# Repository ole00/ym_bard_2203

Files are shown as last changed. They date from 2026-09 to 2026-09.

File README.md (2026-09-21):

# ym_bard_2203
A dual YM2203 sound chip board for Arduino Nano
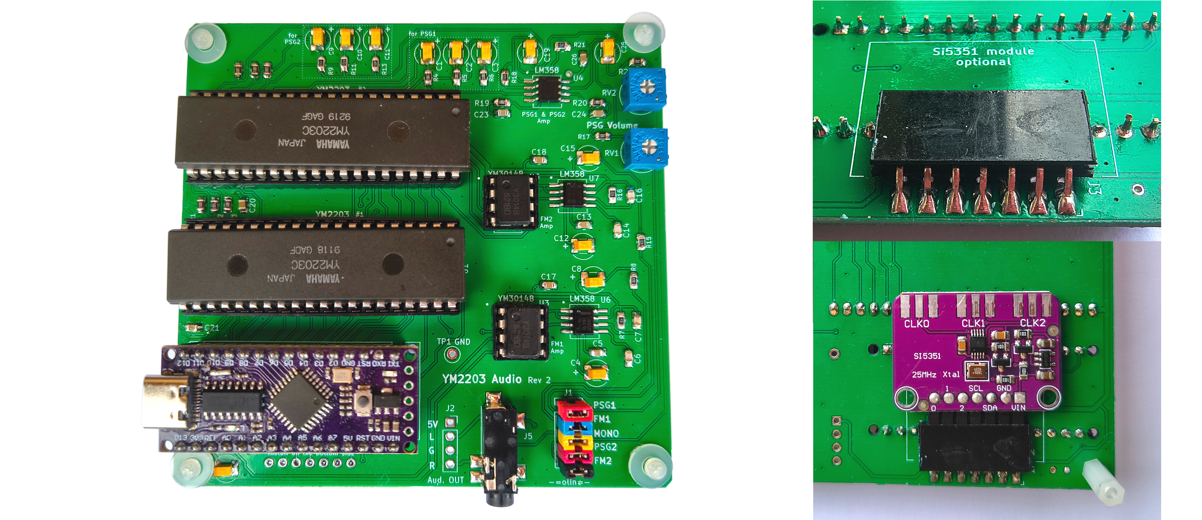
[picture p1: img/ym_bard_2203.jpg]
Board image ym_bard_2203


This is an open source/open hardware sound board with two YM2203 FM sound chips driven by Arduino Nano. 
The YM2203 FM chips were used in several arcade game boards made in 80's. 
The design of the YM Bard sound board was actually based on a schematic of an arcade game.

The board allows you to experiment with YM2203 sound chips by writing the chip's register values
from a PC over a serial port. It is also possible to stream an arcade game sound data over
a serial port from a PC based emulator and produce authentic sound and music of an arcade game.

YM2203 chips are register compatible with AY-3 PSG sound generator, therefore you can use FM Bard
to play AY-3 tunes as well.

Arduino selection
----------------------

The b(o)ard requires and Arduino Nano or a NANO clone. You can use 5V Atmel based Arduino Nano
or Renesas based Arduino NANO R4 or 3.3V ESP32-S3 based Arduino NANO or their clones.
The picture above uses a cheap LGT8F328P Nano board.

YM2203 requires an external clock of specific frequency to produce sounds. The clock can 
be generated either by Arduino NANO or by an external Si5351 module connected on the bottom
side of the YM Bard. The Si5351 module is optional, however the Atmel based Arduino NANO can
only produce limited selection of clock frequencies, so it is recommended to use the module 
in such case. NANO R4 and ESP32-S3 based Arduino NANO can produce various frequencies 
and the clock module is not required for driving the FM clock at 3 MHz.

Audio data streaming
----------------------
To stream data to YM Bard use 'ym2203_streamer.ino' Arduino sketch located in 'arduino-src'
subdirectory and upload it to your Arduino NANO. Use Arduino IDE PC software to upload the sketch.
If you use Arduino NANO ESP32-S3 then make sure to install "esp32 by Espressif" version 3.3.X
board support in Arduino IDE Board manager before you do the upload.

The sketch reads binary data sent from the connected PC serial port (115200 baud rate)
and writes the data to the parallel data bus of the FM chips. The stream format supports two types of packets: 
3 byte packet and 12 byte packet.

**3 byte packet**

* 1st byte: bits 7-4: 0xF, bit 3: 0, bits 2-0: chip selection (0 selects the 1st YM2203, 1 selects the 
  2nd YM2203).
* 2nd byte: register address
* 3rd byte: register value

**12 byte packet**
* 1st byte: bits 7-4: 0xF, bit 3: 1, bits 2-0: chip selection (0 selects the 1st YM2203, 1 selects the 
  2nd YM2203).
* byte 2 to byte 12: register values of register 0 to register 10.

3 byte packet allows you to write single arbitrary register. It is flexible, but requires
more data per register to be sent compared to 12 byte packet. 12 byte packets basically sends
multiple PSG registers in one go, saving the serial line bandwidth.

To start streaming open the serial port of your Arduino NANO and write the packets to
the serial port in binary format.

Example playback
-----------------
If you use Linux you can try to connect YM Bard to Ghost'n Goblins arcade emulator located here:

https://github.com/ole00/arcade_emu_gng

Pass the serial port device of the YM Bard to the emulator with parameter '-fm [device name]'
when starting the emulator. For example add '-fm /dev/ttyUSB0' parameter. If your Arduino NANO
has the 'ym2203_streamer.ino' uploaded, then the emulator and connected YM Bard should start
producing tunes from the arcade game.

Board production
------------------
To produce YM Bard you'll need some basic SMT component soldering skills. All components can be
soldered by hand with a modern soldering iron with controllable temperature (like TS100
or similar) set to 330 to 350 deg C. The list of components is located in 'bom_fm_bard_2203.csv'
file. The PCB can be fabricated by jlcpcb.com, pcbway.com, allpcb.com or other online services. 
Use the zip archive stored in the 'gerbers' directory and upload it to the manufacturer's web site
of your choice. Upload the 'ym2203_r2_fab.zip' archive and set the following parameters (if required). 
  
  * 2 layer board
  * PCB Thickness: 1.6, or 1.2 mm
  * Copper Weight: 1
  * The rest of the options can stay default or choose whatever you fancy (colors, finish etc.)

When populating components either start with the smallest SMT parts first (resistors and small capacitors)
or start with the SOIC-8 LM358 OpAmps so that you have plenty of room for the soldering iron tip.
After that, solder the bigger 10uF capacitors - check the capacitor's polarity. The SMT caps use
the stripe on the positive (+) side, the electrolytic TH caps use the stripe on the negative (-) side.
Solder the through hole parts and the audio connector at the end. 
I strongly recommend to use IC sockets for YM2203C chips and also for YM3014B chips.
IC sockets ensure you do not overheat and damage the chips while soldering. They will also allow
you to swap the chip in case you get faulty chips sourced from Aliexpress (not uncommon).

If you are not familiar with SMT soldering check some YT videos and use one of the YM Bard PCB 
as a practice board to solder some SMT resistors and caps. It is not that hard, just requires
good tweezers, use of soldering flux and a bit of practice.

Audio output
--------------
The output audio signal is routed through J1 'mixing' header. The header is supposed to be populated
by jumper caps that connect individual sound sources to either a stereo or mono output. The sound
sources are FM1, PSG1 (both coming from the YM2203 #1) and FM2 and PSG2 (both coming from YM2203 #2).
Yes, YM2203 chips have separate output for FM channels and for the PSG channels. The PSG channel
volume can be adjusted (relatively to the FM channels) by RV1 and RV2 potentiometers.
The middle jumper position on J1 - when shorted - joins all outputs to a mono signal (routed to
both Left and Right audio channel). By default the jumpers are supposed to be all connected (see the 
YM bard image), but you can undo them if you want to disable certain audio sources from the final output. 
Additionally/optionally you might want to design/add a post processing audio option to YM Bard 
by connecting it via J1 and J2 header (has GND and 5V pins). The output is not amplified but
is capable of driving small headphones via J5 headphone socket. If you want louder sound use
PC speakers with an amplifier connected to the headphone socket.

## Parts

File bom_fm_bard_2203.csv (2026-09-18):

Reference | Value | Qty | Notes
C1,C2,C3,C4,C8,C9,C10,C11,C12,C15,C19,C22,C25 | 10uF | 13 | SMT 1210 or SMT 1208
C5,C13,C17,C18,C20,C21,C23,C24,C26 | 0.1uF | 9 | SMT 0805
C6,C7,C14,C16 | 1nF | 4 | SMT 0805
J1 | AUD_MIX | 1 | header pin 2x5 2.54mm pin pitch TH
J5 | AudioJack3 | 1 | PJ-328 Audio jack
R1,R2,R3,R10,R12,R14,R17,R22 | 1k | 8 | SMT 0805
R4,R5,R6,R7,R8,R9,R11,R13,R15,R16,R18,R21 | 4k7 | 12 | SMT 0805
R19,R20 | 10k | 2 | SMT 0805
RV1,RV2 | 2k | 2 | potentiometer 3362P 2k
U1,U2 | YM2203 | 2 | YM2203C Aliexpress
U3,U5 | YM3014B | 2 | DAC for Yamaha FM chips
U4,U6,U7 | LM358 | 3 | SMT SOIC-8
- | jumper cap | 5 | 2.54mm jumper cap (for audio 'mixer')

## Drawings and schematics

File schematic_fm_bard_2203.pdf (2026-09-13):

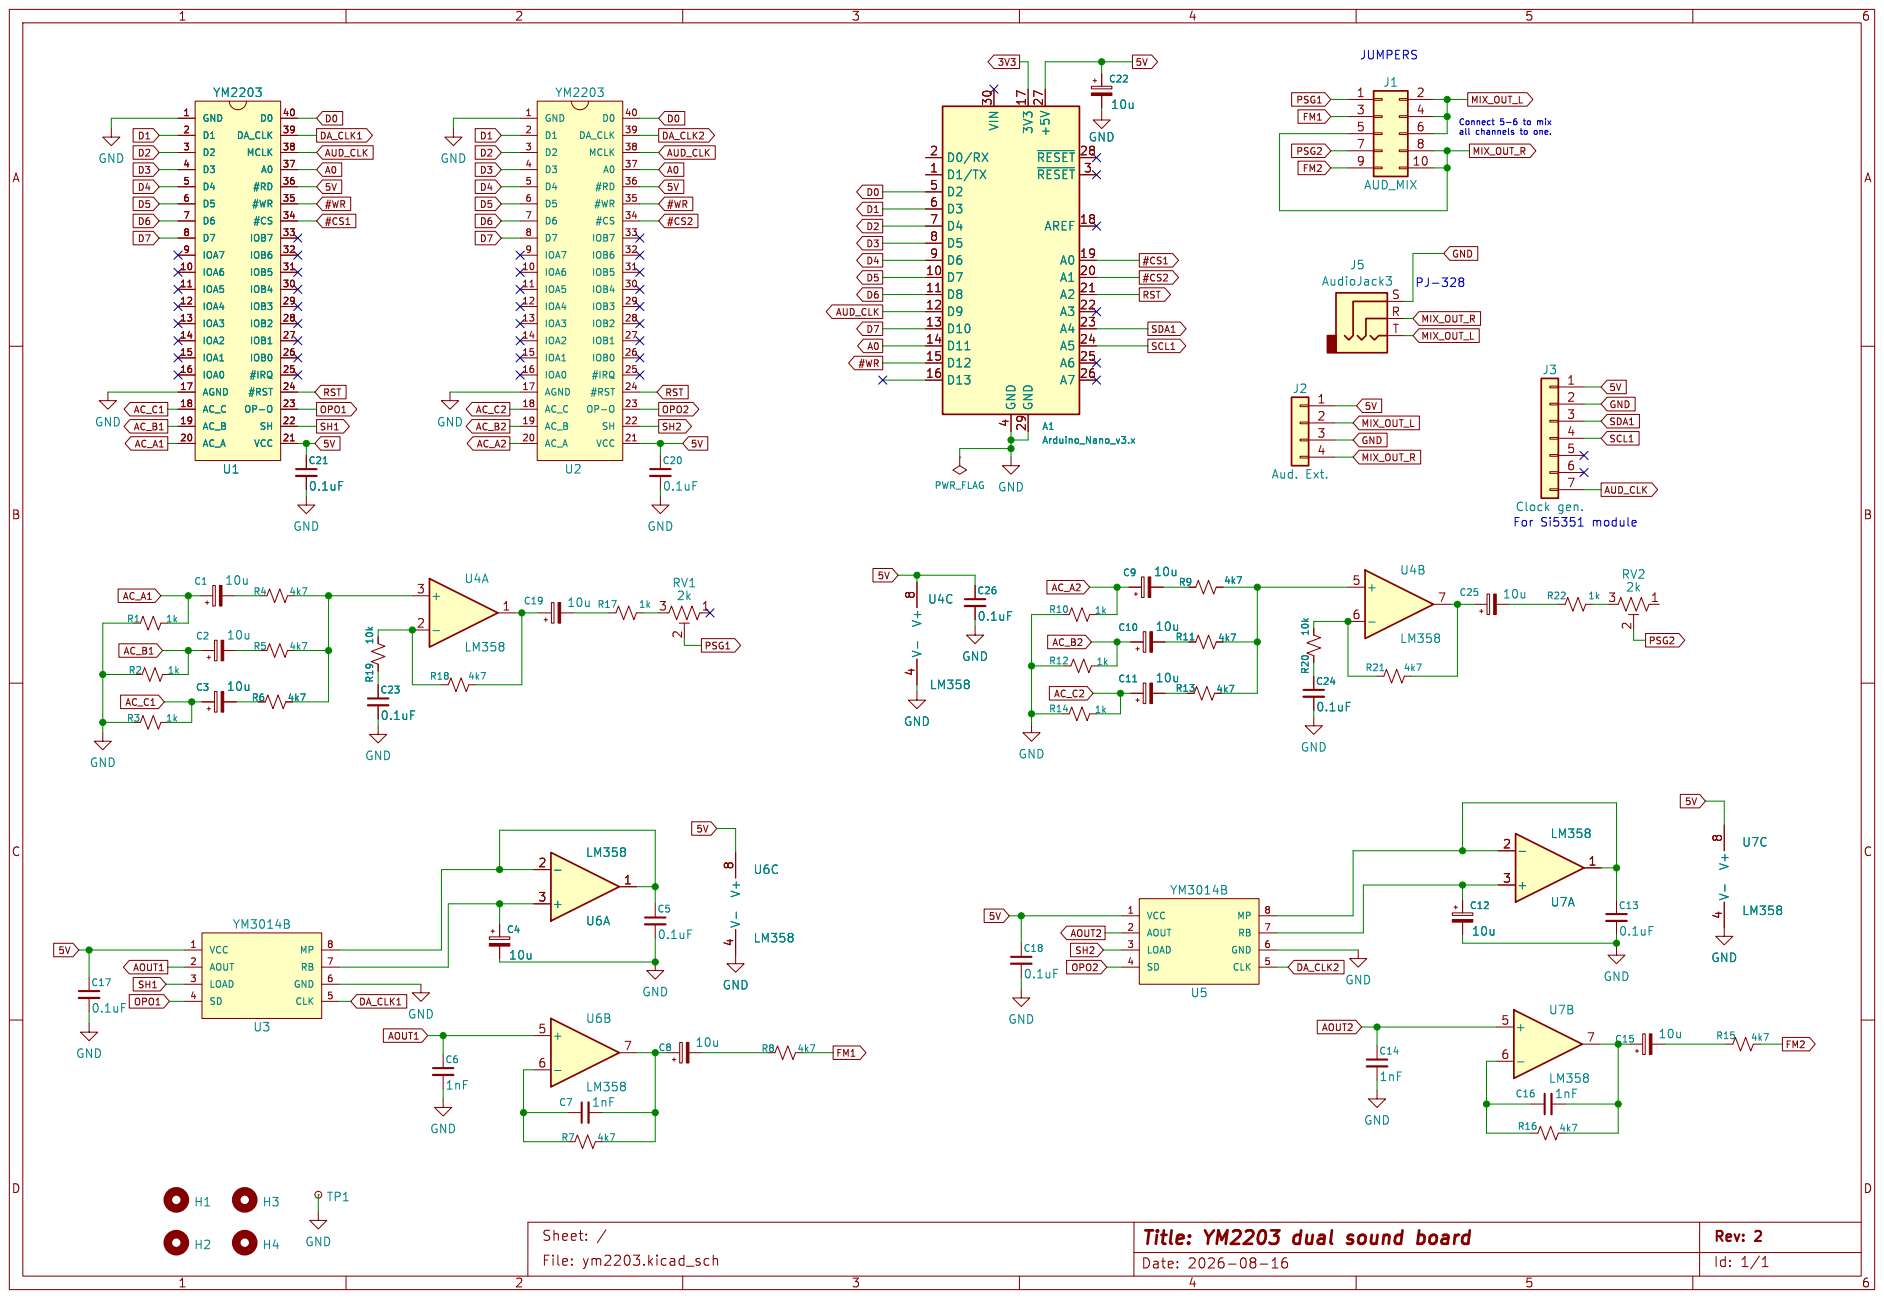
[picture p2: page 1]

Id: 1/1 Title: YM2203 dual sound board

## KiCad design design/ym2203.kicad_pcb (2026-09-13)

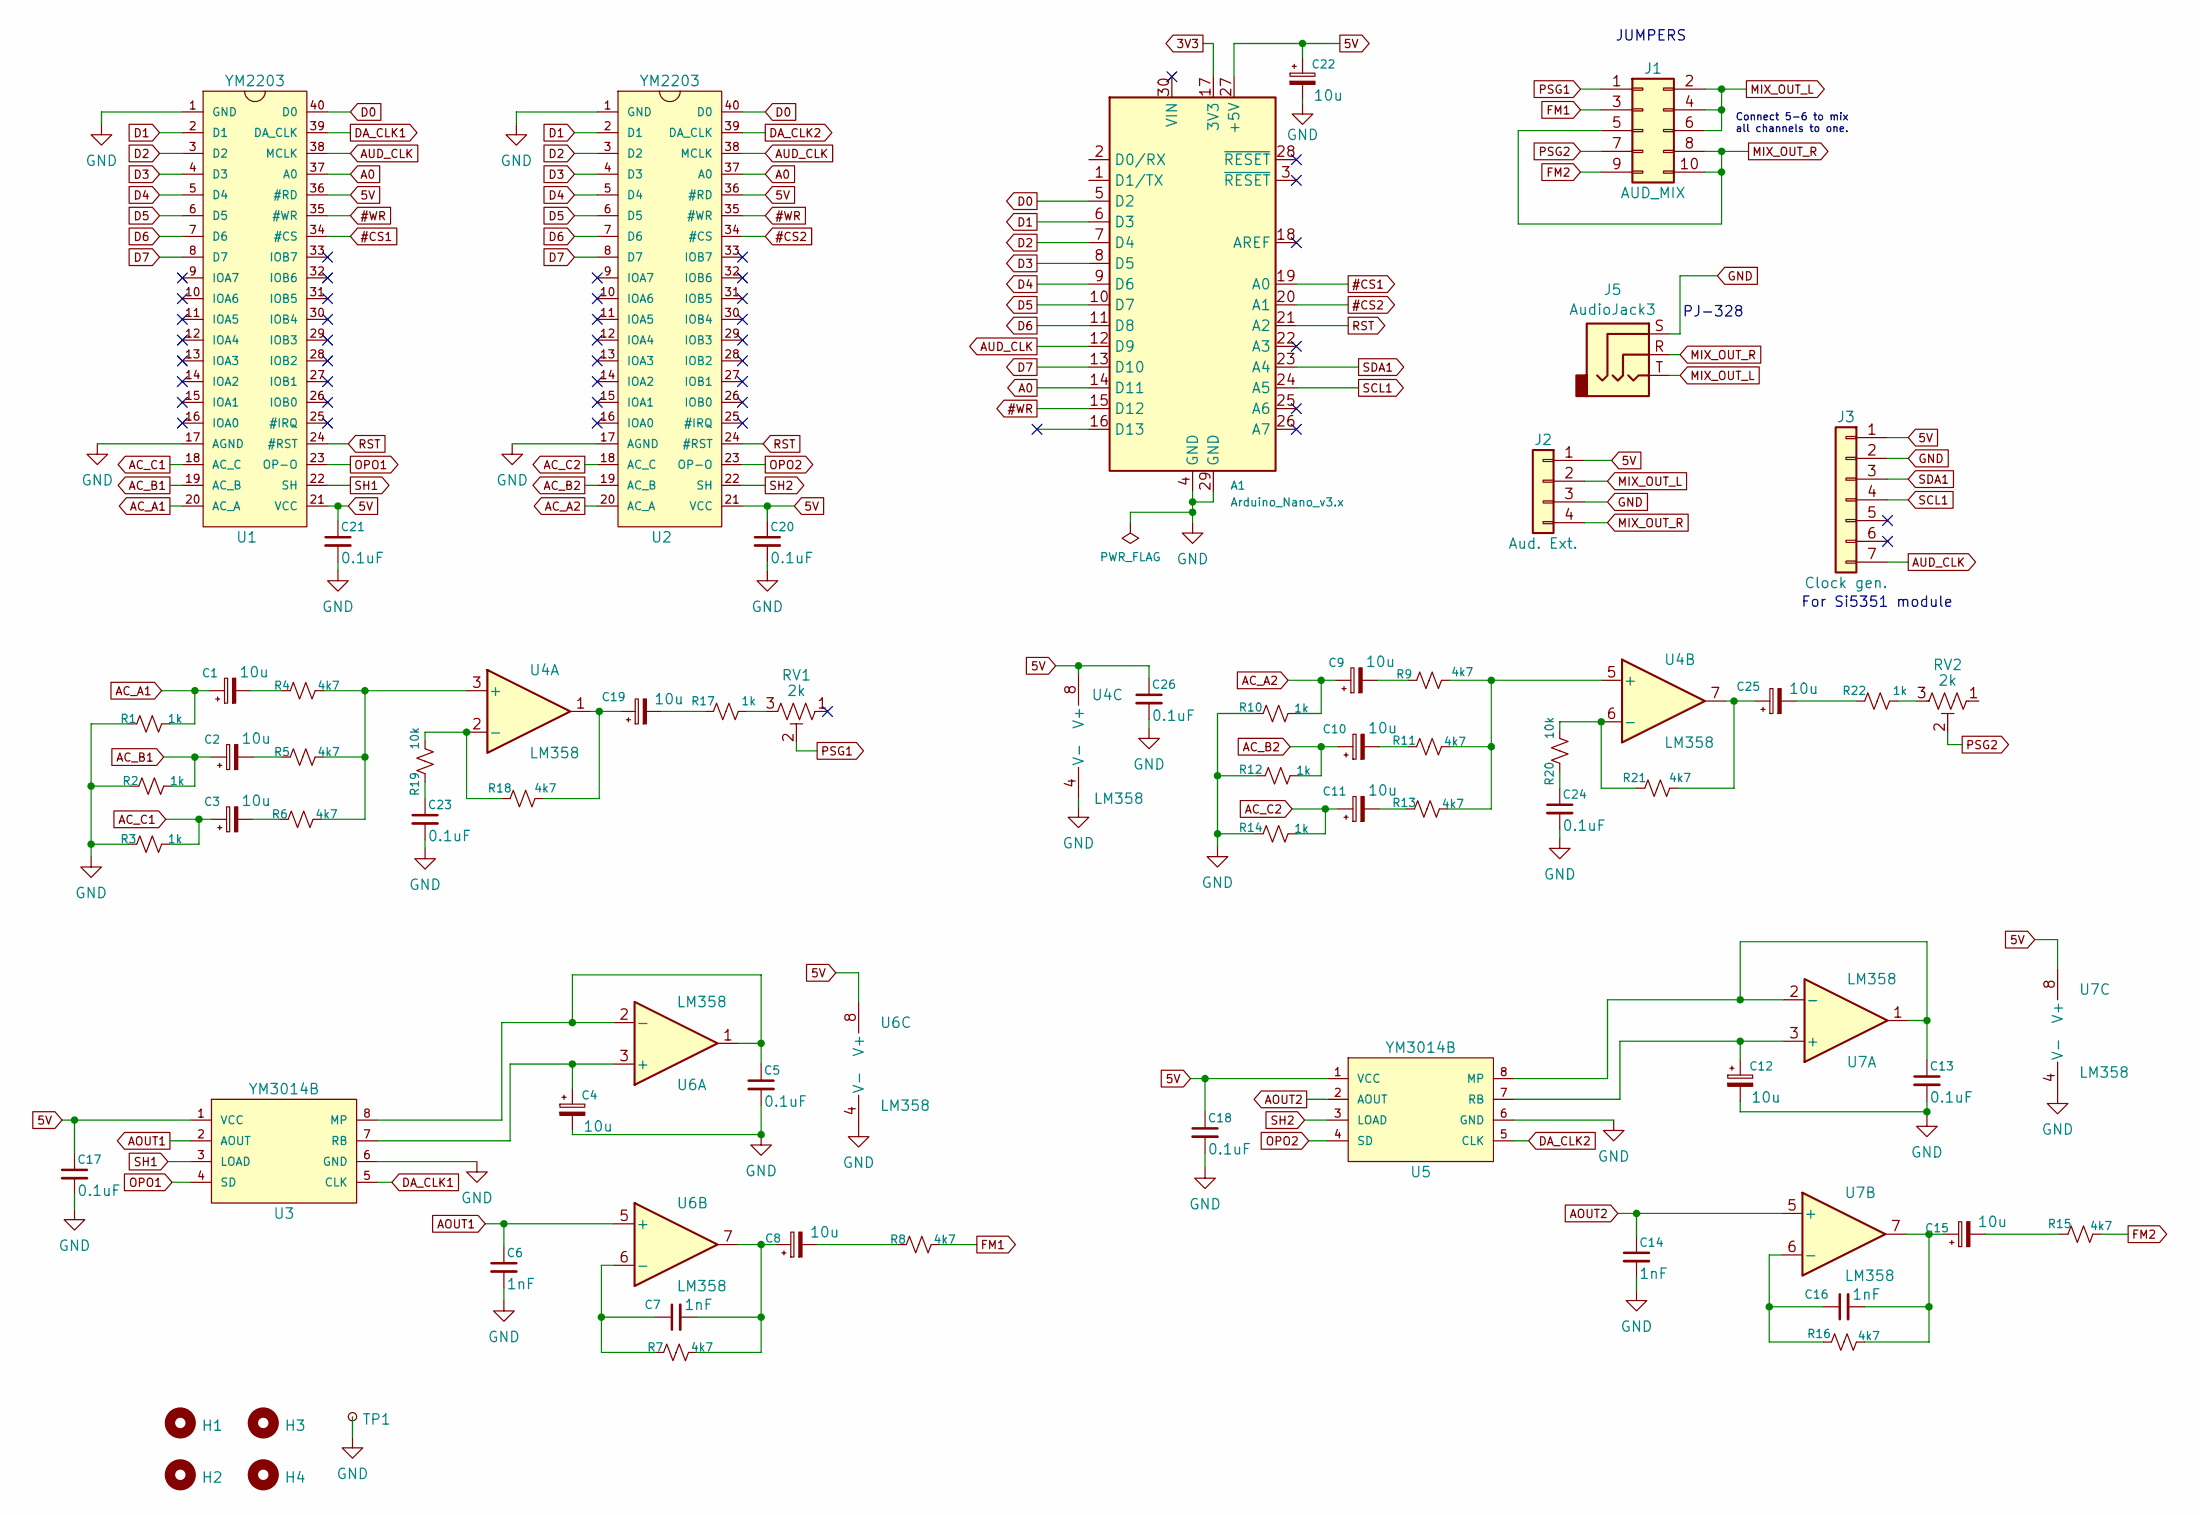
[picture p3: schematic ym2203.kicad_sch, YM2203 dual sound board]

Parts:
A1: Arduino_Nano_v3.x; Arduino_Nano_WithMountingHoles
C1, C2, C3, C4, C8, C9, C10, C11, C12, C15, C19, C22, C25: 10u; C_1210_3225Metric_dual_TH
C5, C13, C17, C18, C20, C21, C23, C24, C26: 0.1uF; C_0805_2012Metric_Pad1.18x1.45mm_HandSolder
C6, C7, C14, C16: 1nF; C_0805_2012Metric_Pad1.18x1.45mm_HandSolder
H1, H2, H3, H4: MountingHole; MountingHole_3.2mm_M3
J1: AUD_MIX; PinHeader_2x05_P2.54mm_Vertical
J2: Aud. Ext.; PinSocket_1x04_P2.54mm_Vertical
J3: Clock gen.; pad_array_th_1x07_P2.54mm
J5: AudioJack3; Jack_3.5mm_CUI_SJ2-3593D-SMT_Horizontal
R1, R2, R3, R10, R12, R14, R17, R22: 1k; R_0805_2012Metric_Pad1.20x1.40mm_HandSolder
R4, R5, R6, R7, R8, R9, R11, R13, R15, R16, R18, R21: 4k7; R_0805_2012Metric_Pad1.20x1.40mm_HandSolder
R19, R20: 10k; R_0805_2012Metric_Pad1.20x1.40mm_HandSolder
RV1, RV2: 2k; Potentiometer_Bourns_3339P_Vertical_HandSoldering
TP1: TestPoint_Small; TestPoint_Loop_D2.50mm_Drill1.0mm
U1, U2: YM2203; DIP-40_W15.24mm_LongPads
U3, U5: YM3014B; DIP-8_W7.62mm
U4, U6, U7: LM358; SO-8_5.3x6.2mm_P1.27mm

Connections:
3V3: A1.17 (3V3)
5V: A1.27 (+5V), C17.1, C18.1, C20.1, C21.1, C22.1, C26.1, J2.1, J3.1, U1.21 (VCC), U1.36 (#RD), U2.21 (VCC), U2.36 (#RD), U3.1 (VCC), U4.8 (V+), U5.1 (VCC), U6.8 (V+), U7.8 (V+)
#CS1: A1.19 (A0), U1.34 (#CS)
#CS2: A1.20 (A1), U2.34 (#CS)
#WR: A1.15 (D12), U1.35 (#WR), U2.35 (#WR)
A0: A1.14 (D11), U1.37 (A0), U2.37 (A0)
AC_A1: C1.1, R1.2, U1.20 (AC_A)
AC_A2: C9.1, R10.2, U2.20 (AC_A)
AC_B1: C2.1, R2.2, U1.19 (AC_B)
AC_B2: C10.1, R12.2, U2.19 (AC_B)
AC_C1: C3.1, R3.2, U1.18 (AC_C)
AC_C2: C11.1, R14.2, U2.18 (AC_C)
AOUT1: C6.1, U3.2 (AOUT), U6.5 (+)
AOUT2: C14.1, U5.2 (AOUT), U7.5 (+)
AUD_CLK: A1.12 (D9), J3.7, U1.38 (MCLK), U2.38 (MCLK)
D0: A1.5 (D2), U1.40 (D0), U2.40 (D0)
D1: A1.6 (D3), U1.2 (D1), U2.2 (D1)
D2: A1.7 (D4), U1.3 (D2), U2.3 (D2)
D3: A1.8 (D5), U1.4 (D3), U2.4 (D3)
D4: A1.9 (D6), U1.5 (D4), U2.5 (D4)
D5: A1.10 (D7), U1.6 (D5), U2.6 (D5)
D6: A1.11 (D8), U1.7 (D6), U2.7 (D6)
D7: A1.13 (D10), U1.8 (D7), U2.8 (D7)
DA_CLK1: U1.39 (DA_CLK), U3.5 (CLK)
DA_CLK2: U2.39 (DA_CLK), U5.5 (CLK)
FM1: J1.3, R8.2
FM2: J1.9, R15.2
GND: A1.4 (GND), A1.29 (GND), C4.2, C5.2, C6.2, C12.2, C13.2, C14.2, C17.2, C18.2, C20.2, C21.2, C22.2, C23.2, C24.2, C26.2, J2.3, J3.2, J5.S, R1.1, R2.1, R3.1, R10.1, R12.1, R14.1, TP1.1, U1.1 (GND), U1.17 (AGND), U2.1 (GND), U2.17 (AGND), U3.6 (GND), U4.4 (V-), U5.6 (GND), U6.4 (V-), U7.4 (V-)
MIX_OUT_L: J1.2, J1.4, J1.6, J2.2, J5.T
MIX_OUT_R: J1.5, J1.8, J1.10, J2.4, J5.R
unnamed: C1.2, R4.1
unnamed: C2.2, R5.1
unnamed: C3.2, R6.1
unnamed: C7.2, C8.1, R7.2, U6.7
unnamed: C8.2, R8.1
unnamed: C9.2, R9.1
unnamed: C10.2, R11.1
unnamed: C11.2, R13.1
unnamed: C15.1, C16.2, R16.2, U7.7
unnamed: C15.2, R15.1
unnamed: C19.1, R18.2, U4.1
unnamed: C19.2, R17.1
unnamed: C23.1, R19.1
unnamed: C24.1, R20.1
unnamed: C25.1, R21.2, U4.7
unnamed: C25.2, R22.1
unnamed: R17.2, RV1.3
unnamed: R22.2, RV2.3
unnamed: C5.1, U3.8 (MP), U6.1, U6.2 (-)
unnamed: C4.1, U3.7 (RB), U6.3 (+)
unnamed: R4.2, R5.2, R6.2, U4.3 (+)
unnamed: R18.1, R19.2, U4.2 (-)
unnamed: R9.2, R11.2, R13.2, U4.5 (+)
unnamed: R20.2, R21.1, U4.6 (-)
unnamed: C13.1, U5.8 (MP), U7.1, U7.2 (-)
unnamed: C12.1, U5.7 (RB), U7.3 (+)
unnamed: C7.1, R7.1, U6.6 (-)
unnamed: C16.1, R16.1, U7.6 (-)
OPO1: U1.23 (OP-O), U3.4 (SD)
OPO2: U2.23 (OP-O), U5.4 (SD)
PSG1: J1.1, RV1.2
PSG2: J1.7, RV2.2
RST: A1.21 (A2), U1.24 (#RST), U2.24 (#RST)
SCL1: A1.24 (A5), J3.4
SDA1: A1.23 (A4), J3.3
SH1: U1.22 (SH), U3.3 (LOAD)
SH2: U2.22 (SH), U5.3 (LOAD)

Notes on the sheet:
For Si5351 module
PJ-328
JUMPERS
Connect 5-6 to mix all channels to one.

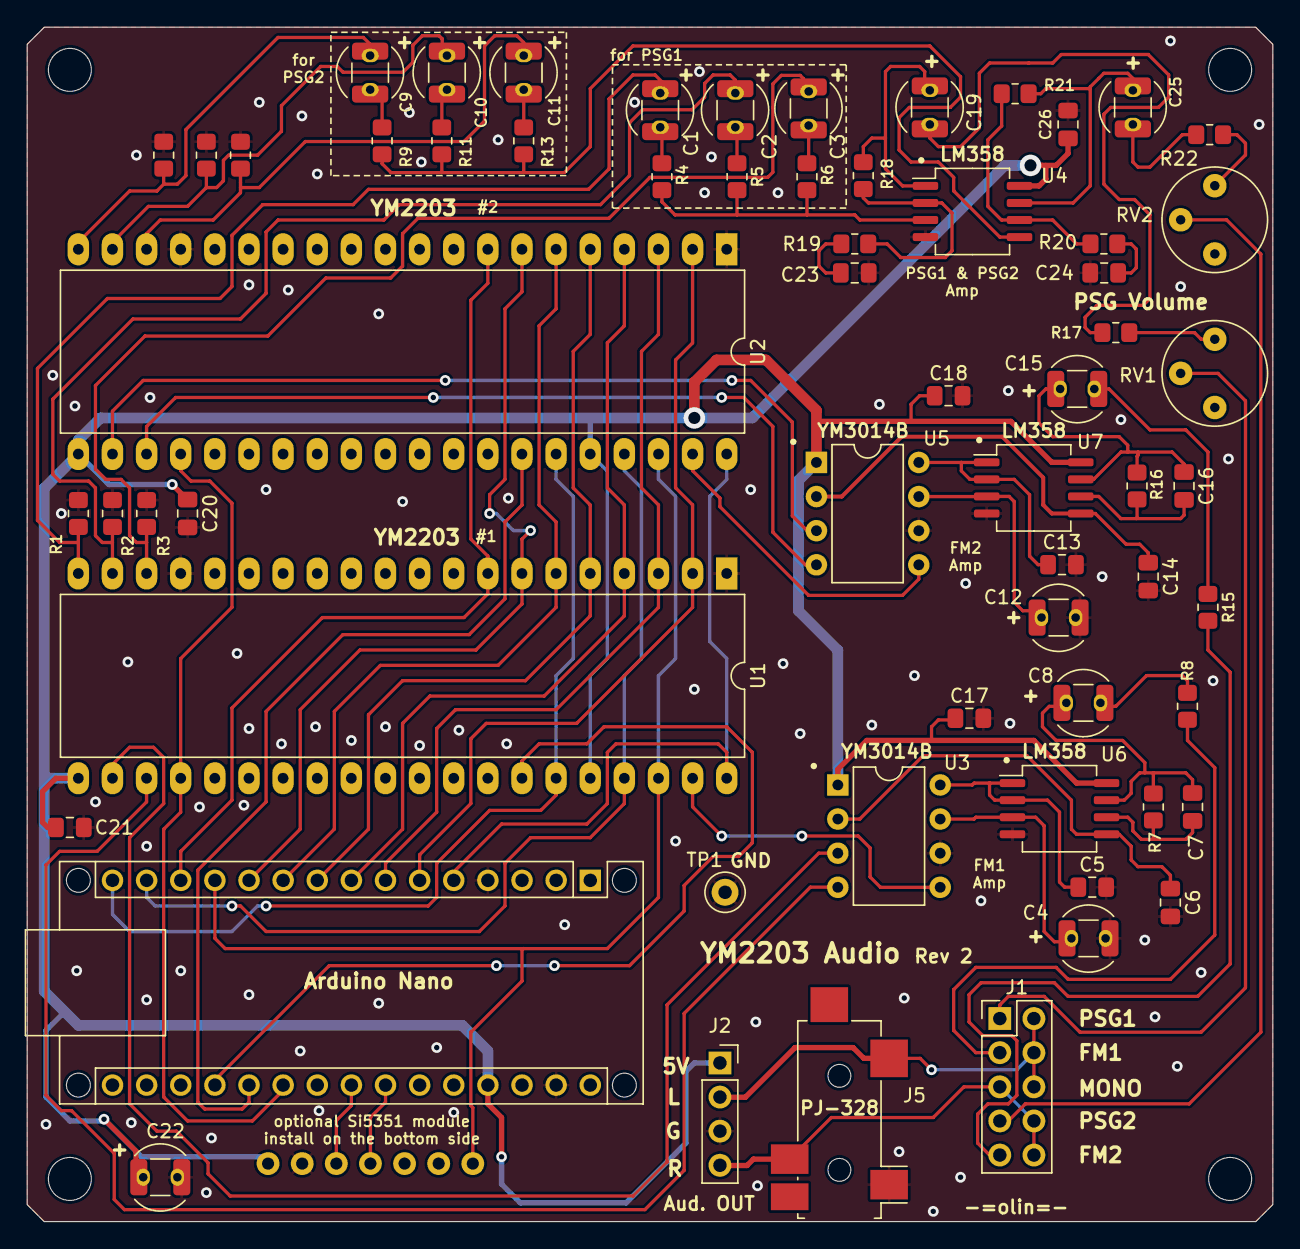
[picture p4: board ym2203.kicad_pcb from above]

Board: 2 copper layers, 92.7 x 88.9 mm, 67 parts (1 on the bottom side), 66 nets.

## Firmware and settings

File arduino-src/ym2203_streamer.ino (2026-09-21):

// YM2203 streamer for Arduino Nano and Arduino NANO-ESP32 and compatible
// Streams up to two YM2203 chips.

#include "si5351.h"

#ifdef CONFIG_IDF_TARGET_ESP32S3
#define USE_ESP32S3
#endif

#ifdef _RENESAS_RA_
#include "pwm.h"
#define USE_RENESAS_RA
#endif


#ifdef USE_ESP32S3
#define USE_FAST_MCU
#define PIN_CS1 1
#define PIN_CS2 2

#define PIN_WR  47
#define PIN_RESET 3

#define PIN_DB0 5
#define PIN_DB1 6
#define PIN_DB2 7
#define PIN_DB3 8
#define PIN_DB4 9
#define PIN_DB5 10
#define PIN_DB6 17
#define PIN_DB7 21
#define PIN_ADDR 38
#define PIN_YM_CLK 18

#define PIN_BOARD_LED 45
#define LED_INVERSE 1

#elif defined(USE_RENESAS_RA)
// Renesas based Arduino NANO R4
#define USE_FAST_MCU
#define PIN_CS1 A0
#define PIN_CS2 A1

#define PIN_WR  12
#define PIN_RESET A2

#define PIN_DB0 2
#define PIN_DB1 3
#define PIN_DB2 4
#define PIN_DB3 5
#define PIN_DB4 6
#define PIN_DB5 7
#define PIN_DB6 8
#define PIN_DB7 10
#define PIN_ADDR 11
#define PIN_YM_CLK 9

#define PIN_BOARD_LED LED_BUILTIN
#define LED_INVERSE 0
#else
// Atmega based arduinos
#define PIN_CS1 A0
#define PIN_CS2 A1

#define PIN_WR  12
#define PIN_RESET A2

#define PIN_DB0 2
#define PIN_DB1 3
#define PIN_DB2 4
#define PIN_DB3 5
#define PIN_DB4 6
#define PIN_DB5 7
#define PIN_DB6 8
#define PIN_DB7 10
#define PIN_ADDR 11
#define PIN_YM_CLK 9

#define PIN_BOARD_LED LED_BUILTIN
#define LED_INVERSE 0

#define M_D0 (1 << PIN_DB0)
#define M_D1 (1 << PIN_DB1)
#define M_D2 (1 << PIN_DB2)
#define M_D3 (1 << PIN_DB3)
#define M_D4 (1 << PIN_DB4)
#define M_D5 (1 << PIN_DB5)
#define M_D6 (1 << (PIN_DB6 - 8))
#define M_D7 (1 << (PIN_DB7 - 8))
#define M_WR (1 << (PIN_WR - 8))
#define M_ADDR (1 << (PIN_ADDR - 8))

#endif


#define MAGIC 0xF3

#define XON  0x11
#define XOFF 0x13

// Hysteresis Levels for a 256-byte buffer
#define BUFFER_HIGH_WATER 96 // Send XOFF if buffer fills past this
#define BUFFER_LOW_WATER  14  // Send XON if buffer empties below this

#define LOCAL_FIFO_SIZE 128
uint8_t localFifo[LOCAL_FIFO_SIZE];
uint8_t fifoHead = 0;
uint8_t fifoTail = 0;
uint8_t parserState = 0;


bool masterTxPaused = false; // Tracks if we told Linux to stop

// Set up 3MHz clock for YM2203 on pin D9
#ifdef USE_ESP32S3
void setupPwm() {
    // 1. MANDATORY ELEMENT: Force the LEDC system driver to hook into 
    // the 80 MHz APB clock instead of the default 40 MHz XTAL clock source.
    ledcSetClockSource(LEDC_AUTO_CLK); 

    uint32_t frequency = 3000000; // Exactly 3,000,000 Hz
    uint8_t resolution_bits = 1;   // 4-bit resolution 

    // 2. Attach the pin to the high-speed clock bus
    ledcAttach(PIN_YM_CLK, frequency, resolution_bits);

    // 3. Write a 50% duty cycle square wave
    ledcWrite(PIN_YM_CLK, 1); 
}
#elif defined(USE_RENESAS_RA)
 //Arduino NANO R4 (Renesas ARM at 5V)
 void setupPwm() {
    PwmOut* high_speed_clock = new PwmOut(PIN_YM_CLK);

    // Configure HS clock via the core's native raw microsecond parameter initialization.
    // Arguments: (period_units, pulse_width_units, raw_mode_flag, timer_divider)
    // To get 3MHz signal from the 48MHz background bus clock (PCLKD):
    // Period Cycles = 48,000,000 / 3,000,000 = 16 cycles
    // Duty Cycle (50% Square Wave) = 16 / 2 = 8 cycles
    uint32_t period_cycles = 16;
    uint32_t pulse_cycles = 8;

    // Passing 'true' alerts the driver to use raw CPU clock cycles 
    // instead of abstract microsecond timing blocks.
    bool success = high_speed_clock->begin(
        period_cycles, 
        pulse_cycles, 
        true, 
        TIMER_SOURCE_DIV_1
    );
 }
#else
// Atmega 328p or compatible
// Can't produce 3MH clock, the closest match is 3.2MHz.
void setupPwm() {
  // Set Pin 9 (Port B, Pin 1) as an OUTPUT
  pinMode(PIN_YM_CLK, OUTPUT);

  // 1. Clear Timer 1 Control Registers
  TCCR1A = 0;
  TCCR1B = 0;
  TCNT1  = 0;

  // 2. Set Fast PWM mode with ICR1 as the TOP value (Mode 14)
  // WGM13 and WGM12 are in TCCR1B. WGM11 is in TCCR1A.
  TCCR1A |= (1 << WGM11);
  TCCR1B |= (1 << WGM13) | (1 << WGM12);

  // 3. Set Toggle/Clear behavior for Channel A (Pin 9)
  // This toggles Pin 9 on every match to create the 8 MHz wave
  TCCR1A |= (1 << COM1A1);

  // 4. Set TOP to 1. 
  // Formula: Frequency = Clock / (Prescaler * (1 + TOP))
  // 8,000,000 = 16,000,000 / (1 * (1 + 1))
  //ICR1 = 1; // 8MHz
  //ICR1 = 2; // 5.333 MHz
  //ICR1 = 3; // 4.0 MHz
  ICR1 = 4; // 3.2 MHz
  //ICR1 = 5; // 2.66 MHz
  //ICR1 = 6; // 2.28 MHz
  //ICR1 = 7; // 2 MHz
  //ICR1 = 8; // 1.77 MHz
  //ICR1 = 9; // 1.6 MHz
  //ICR1 = 10; // 1.45 MHz


  // 5. Set the Match value to 0 to trigger the toggle
  OCR1A = 1; // set to 0 for 8 MHz, set to 1 for up to 3.2 MHz, set to 2 for lower

  // 6. Start the timer with NO prescaler (divide clock by 1)
  TCCR1B |= (1 << CS10);
}
#endif


// Setup clock for YM2203. Use Si5251 clock generator if present, or else
// try to generate 3 MHz clock on pin D9.
static void setupClockOutput() {
    // Check whether we have Si5351 programmable clock.
    // If so, set 3 Mhz clock.
    if (Si5351_init()) {
        Si5351_set_3_mhz();
        digitalWrite(PIN_BOARD_LED, LED_INVERSE ? LOW : HIGH);
    } else
    // Fallback method of using PWM based clock.
    // Closest possible frequency is 3.2 MHz on Atmel arduinos, so music is a bit higher pitch.
    // ESP32-S3 based Arduinos can generate precise 3MHz clock frequency on their own.
    {    
        digitalWrite(PIN_BOARD_LED, LED_INVERSE ? HIGH : LOW); 
        setupPwm();
    }
}

// read bytes from serial port into an internal FIFO buffer
static inline uint8_t prefetchSerialBytes(uint8_t max, bool wait = false) {
#ifdef USE_FAST_MCU
    unsigned long time;
    unsigned long startWait = micros();
#endif    
    while (Serial.available() > 0) {
        uint8_t nextHead = (fifoHead + 1) & 0x7F; //% LOCAL_FIFO_SIZE;
        if (nextHead != fifoTail) { // Prevent local overflow
            localFifo[fifoHead] = Serial.read();
            fifoHead = nextHead;
            max--;
            if (!max) {
                break;
            }
        } else {
            break; // Local FIFO is full, stop reading
        }
    }
#ifdef USE_FAST_MCU
    if (wait) {
        time = (micros() - startWait);
        if (time < max)  {
            delayMicroseconds(max - time);
        }
    }
#endif    

    return max;
}

#ifdef USE_FAST_MCU
// Write a byte to the data bus, also set the address bit.
// This is a generic function for fast MCUs.
static void writeDataBus(uint8_t value, uint8_t data) {
    digitalWrite(PIN_ADDR, data); // Address 0,  Data 1
    prefetchSerialBytes(12, true);

    digitalWrite(PIN_DB0, value & 1);
    value >>= 1;
    digitalWrite(PIN_DB1, value & 1);
    value >>= 1;
    digitalWrite(PIN_DB2, value & 1);
    value >>= 1;
    digitalWrite(PIN_DB3, value & 1);
    value >>= 1;
    digitalWrite(PIN_DB4, value & 1);
    value >>= 1;
    digitalWrite(PIN_DB5, value & 1);
    value >>= 1;
    digitalWrite(PIN_DB6, value & 1);
    value >>= 1;
    digitalWrite(PIN_DB7, value & 1);

    prefetchSerialBytes(12, true);

    digitalWrite(PIN_WR, 0);

    prefetchSerialBytes(8, true);
    digitalWrite(PIN_WR, 1);
}
#else
// Write a byte to the data bus, also set the address bit.
// This is Atmel specific function with fast GPIO access.
static void writeDataBus(uint8_t value, uint8_t data) {
    // set Address line
    if (data) {
        PORTB |= M_ADDR;
    } else {
        PORTB &= ~M_ADDR;
    }
    prefetchSerialBytes(12);

    // set data bus
    if (value & 1) {
        PORTD |= M_D0;
    } else {
        PORTD &= ~M_D0;
    }
    value >>= 1;

    if (value & 1) {
        PORTD |= M_D1;
    } else {
        PORTD &= ~M_D1;
    }
    value >>= 1;

    if (value & 1) {
        PORTD |= M_D2;
    } else {
        PORTD &= ~M_D2;
    }
    value >>= 1;

    if (value & 1) {
        PORTD |= M_D3;
    } else {
        PORTD &= ~M_D3;
    }
    value >>= 1;

    if (value & 1) {
        PORTD |= M_D4;
    } else {
        PORTD &= ~M_D4;
    }
    value >>= 1;

    if (value & 1) {
        PORTD |= M_D5;
    } else {
        PORTD &= ~M_D5;
    }
    value >>= 1;

    if (value & 1) {
        PORTB |= M_D6;
    } else {
        PORTB &= ~M_D6;
    }
    value >>= 1;

    if (value & 1) {
        PORTB |= M_D7;
    } else {
        PORTB &= ~M_D7;
    }
    prefetchSerialBytes(12);

    // pulse Write line
    PORTB &= ~M_WR;
    prefetchSerialBytes(8);
    PORTB |= M_WR;
}
#endif

// High level function that writes a byte to specific YM2203 register.
// chip: 0 or 1 - which YM2203 to target
// addr: register address
// value: register value
static void writeRegister(uint8_t chip, uint8_t addr, uint8_t value) {
    uint8_t csPin = chip ? PIN_CS2 : PIN_CS1;
    digitalWrite(csPin, LOW); 

    writeDataBus(addr, 0);
    writeDataBus(value, 1);

    digitalWrite(csPin, HIGH); 
}

// Reset both YM2203 chips by toggling their Reset pin.
static void resetFm() {
    digitalWrite(PIN_RESET, HIGH);  // Release Reset
    delay(10); 
    digitalWrite(PIN_RESET, LOW);   // Pull Reset low
    delay(5);                       // Hold for a few milliseconds
    digitalWrite(PIN_RESET, HIGH);  // Release Reset
    delay(10); 

}

void setup() {
    Serial.begin(115200);

    pinMode(PIN_BOARD_LED, OUTPUT);
    setupClockOutput();

    // Set Chip select pins
    pinMode(PIN_CS1, OUTPUT);   
    digitalWrite(PIN_CS1, HIGH); 

    pinMode(PIN_CS2, OUTPUT);   
    digitalWrite(PIN_CS2, HIGH); 

    // Setup Write pin
    pinMode(PIN_WR, OUTPUT);
    digitalWrite(PIN_WR, HIGH);

    // Setup data bus pins
    pinMode(PIN_DB0, OUTPUT);
    pinMode(PIN_DB1, OUTPUT);
    pinMode(PIN_DB2, OUTPUT);
    pinMode(PIN_DB3, OUTPUT);
    pinMode(PIN_DB4, OUTPUT);
    pinMode(PIN_DB5, OUTPUT);
    pinMode(PIN_DB6, OUTPUT);
    pinMode(PIN_DB7, OUTPUT);
    pinMode(PIN_ADDR, OUTPUT);

    pinMode(PIN_RESET, OUTPUT);

    resetFm();
    Serial.write(XON);
    localFifo[0] = 0;
    fifoHead = 0;
    fifoTail = 0;
    parserState = 0;
}

void loop() {

    // Try to read serial port bytes into local FIFO buffer.
    prefetchSerialBytes(32);

    // Process bytes from our local buffer
    while (fifoTail != fifoHead) {
        uint8_t streamData;
        uint8_t streamAddr;
        uint8_t streamChip;
        uint8_t packetType;
        uint8_t b = localFifo[fifoTail];
        uint8_t buffered = fifoHead > fifoTail ? fifoHead - fifoTail : fifoHead + LOCAL_FIFO_SIZE - fifoTail;
        fifoTail = (fifoTail + 1) & 0x7F; //% LOCAL_FIFO_SIZE;


        // Check if the buffer is filling up too fast
        if (!masterTxPaused && buffered > BUFFER_HIGH_WATER) {
            Serial.write(XOFF); // Tell master to FREEZE transmission
            masterTxPaused = true;
        } else
        if (masterTxPaused && buffered < BUFFER_LOW_WATER) {
            Serial.write(XON); // Tell master it is safe to RESUME pushing data
            masterTxPaused = false;
        }
        switch (parserState) {
            // first byte: Top nibble is MAGIC (0xF), bit 3 defines packet type, bits 2 to 0
            // define FM chip index.
            case 0: 
                packetType = (b & 0xF8);
                // short 3 byte packet
                if (packetType == 0xF0) {
                    parserState = 1;
                } 
                 else
                // long 12 byte packet
                if (packetType == 0xF8) {
                    parserState = 3;
                }               
                streamChip = b & 0x7;
                prefetchSerialBytes(12);
                break;
            // Short packet: 2nd byte - read register address to set
            case 1:
                streamAddr = b;
                parserState = 2;
                prefetchSerialBytes(12);
                break;
            // Short packet: 3rd byte - read register value to set
            // then write the value to the register
            case 2: 
                streamData = b;
                // special combination of address and data resets the YM chips
                if (streamAddr == 0xFF && streamData == 0xFF) {
                    resetFm();
                } else {
                    writeRegister(streamChip, streamAddr, streamData);
                }
                parserState = 0; 
                break;
            default:
                // handle data bytes of a long packet
                // 11 bytes of register 0 to register 10 are processed
                streamAddr = parserState - 3;
                // check exit condition that forces to read header magic
                if (streamAddr == 10) {
                    parserState = 0; // read header magic
                } else {
                    parserState++;
                }
                writeRegister(streamChip, streamAddr, b);
        }
    }  

}

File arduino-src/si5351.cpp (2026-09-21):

#include "si5351.h"

#if USE_SI5351_CLOCK
#include <Wire.h>
#include <Arduino.h>

#ifdef CONFIG_IDF_TARGET_ESP32S3
#define USE_ESP32S3
#endif

#ifdef _RENESAS_RA_
#define USE_RENESAS_RA
#endif

#ifdef USE_ESP32S3
#define PIN_I2C_SDA 11
#define PIN_I2C_SCL 12
#define I2C_COMMA ,

#elif defined (USE_RENESAS_RA)
// NANO R4 does not support I2C pin configuration, hardwires I2C pins to A4 and A5
#define PIN_I2C_SDA
#define PIN_I2C_SCL
#define I2C_COMMA 
#else
#define PIN_I2C_SDA 
#define PIN_I2C_SCL
#define I2C_COMMA
#endif

#define SI5351_ADDRESS 0x60

// Simple helper function to write data to a specific Si5351 register
static void writeSiRegister(uint8_t reg, uint8_t value) {
  Wire.beginTransmission(SI5351_ADDRESS);
  Wire.write(reg);   // Target register address
  Wire.write(value); // Data byte to write
  Wire.endTransmission();
}

static uint8_t readSiRegister(uint8_t regAddress) {
  // Step 1: Tell the Si5351 which register you want to read
  Wire.beginTransmission(SI5351_ADDRESS);
  Wire.write(regAddress);
  
  // The 'false' parameter sends a "Repeated Start".
  // This keeps the I2C line open so no other device interrupts the read.
  Wire.endTransmission(false); 

  // Step 2: Request 1 byte of data from the Si5351
  Wire.requestFrom(SI5351_ADDRESS, 1);
  
  // Step 3: Wait for the byte to arrive and return it
  if (Wire.available()) {
    return Wire.read();
  } 
  return 0xFF; // Return an error code if the bus fails to read
}

bool Si5351_init() {

    Wire.begin(PIN_I2C_SDA I2C_COMMA PIN_I2C_SCL);

    uint8_t r = readSiRegister(183);

    //Chip not detected
    if (r == 0xFF) {
        return false;
    }
    // Disable all clock outputs first (Register 3)
    // Writing 0xFF turns off all outputs so we can configure safely    
    writeSiRegister(3, 0xFF);

    // Reset the internal Crystal Load Capacitance (Register 183)
    // Most breakout boards use a 10pF crystal (0x80 sets it to 10pF)
    writeSiRegister(183, 0x80);
    return true;
}


void Si5351_set_3_mhz() {

  writeSiRegister(3, 0xFF);

  // 2. Set Crystal Load Capacitance to 10pF (Register 183 = 0x80)
  writeSiRegister(183, 0x80);

  // Set PLL to 600 MHz (24 * 25 MHz crystal) and divide it by 200 to get 3MHz
  // 3. Split up the working Multiplier (PLL A) into single register writes
  // multiplier 24:  128 * 24 => 3072, 3072 - 512 => 2560 (0xA00)
  writeSiRegister(26, 0x00);
  writeSiRegister(27, 0x01);
  writeSiRegister(28, 0x00); // Top most byte
  writeSiRegister(29, 0x0A); // Mid byte
  writeSiRegister(30, 0x00); // Low byte

  // 4. Split up the working Divider (Multisynth 0) into single register writes
  // divider 200: 128 * 200 => 25600, 25600 - 512 => 25088 (0x6200)
  writeSiRegister(42, 0x00);
  writeSiRegister(43, 0x01);
  writeSiRegister(44, 0x00); // Top most byte
  writeSiRegister(45, 0x62); // Mid byte
  writeSiRegister(46, 0x00); // Low byte

  // 5. Configure CLK0 Control pin behavior (Register 16 = 0x4F)
  writeSiRegister(16, 0x4F);

  // 6. Reset both internal PLLs to synchronize (Register 177 = 0xAC)
  writeSiRegister(177, 0xAC);

  // 7. Enable CLK0 output pin (Register 3 = 0xFE)
  writeSiRegister(3, 0xFE);

}

#else
bool detectSi5351() {
    return false;
}
void Si5351_set_3_mhz() {
}
#endif

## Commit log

2026-09-13 added PCB image
2026-09-18 added bill of materials
    [bom_fm_bard_2203.csv]
2026-09-21 Streamer: added support for Arduino NANO R4
    Pin names had to be renamed not to clash with Renesas
    macro symbols.
